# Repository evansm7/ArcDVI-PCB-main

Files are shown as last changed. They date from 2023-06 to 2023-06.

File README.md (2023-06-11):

# ArcDVI main board

Kicad 6.0 PCB design for the ArcDVI main board:

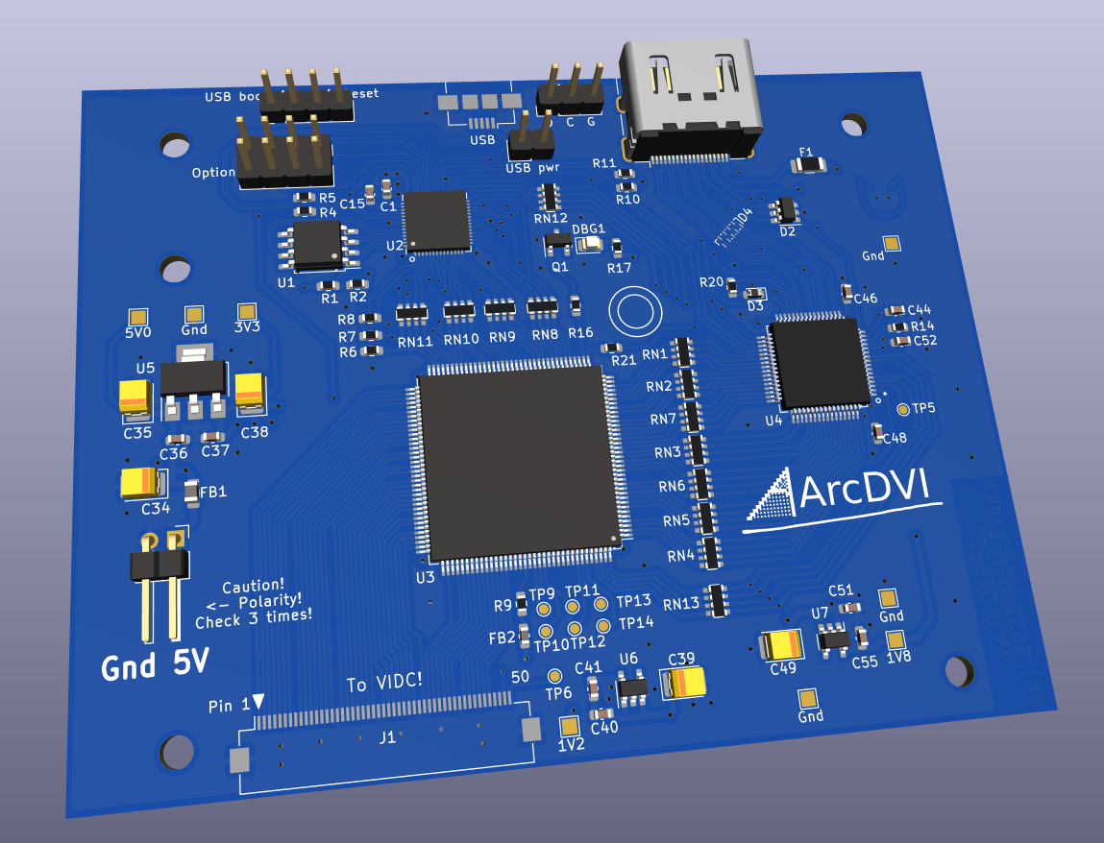
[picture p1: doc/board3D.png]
3D board


This board interfaces via FFC to an ArcDVI VIDC board (either the socket-based interposer for A4xx machines, or the push-on for A3000/A5000).

See <https://stardot.org.uk> for more info.

# License

ArcDVI is copyright 2023 Matt Evans.

This work is licensed under the Creative Commons Attribution-NonCommercial-ShareAlike 3.0 Unported License. To view a copy of this license, visit http://creativecommons.org/licenses/by-nc-sa/3.0/ or send a letter to Creative Commons, PO Box 1866, Mountain View, CA 94042, USA.

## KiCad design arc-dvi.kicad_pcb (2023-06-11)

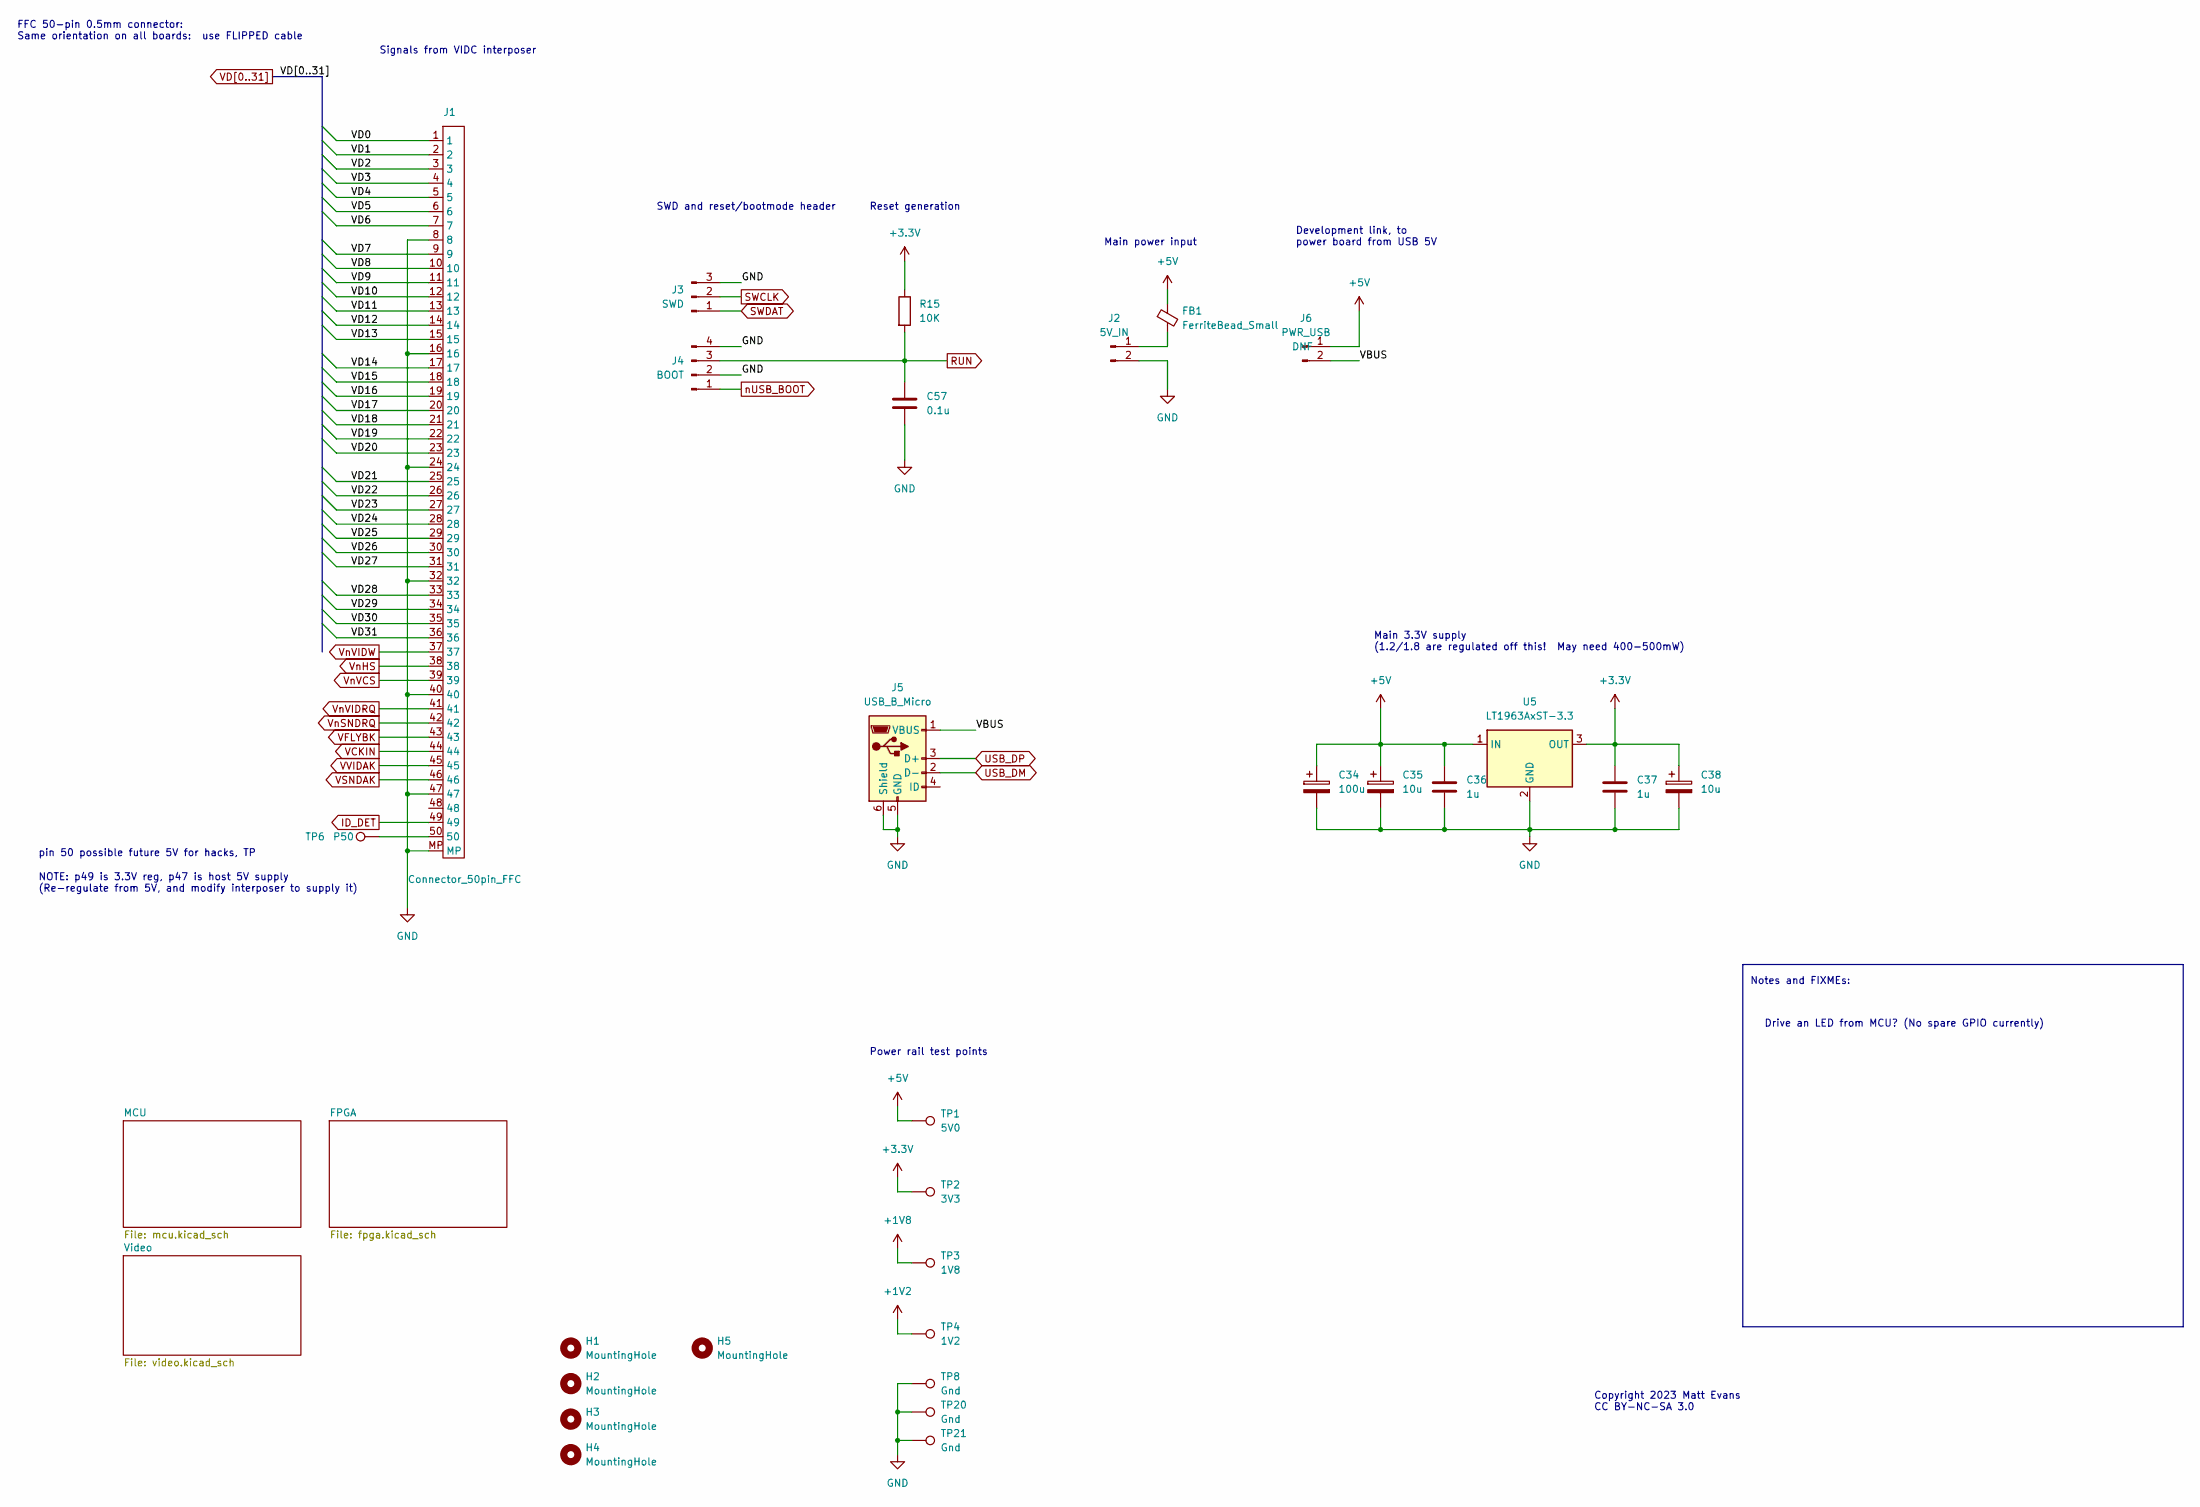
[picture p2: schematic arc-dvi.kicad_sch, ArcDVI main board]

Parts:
C34: 100u; CP_EIA-3528-21_Kemet-B
C35, C38: 10u; CP_EIA-3528-21_Kemet-B
C36, C37: 1u; C_0603_1608Metric
C57: 0.1u; C_0603_1608Metric
FB1: FerriteBead_Small; L_0805_2012Metric
H1, H2, H3, H4, H5: MountingHole; MountingHole_3.2mm_M3
J1: Connector_50pin_FFC; Hirose_FH12-50S-0.5SH_1x50-1MP_P0.50mm_Horizontal
J2: 5V_IN; PinHeader_1x02_P2.54mm_Horizontal
J3: SWD; PinHeader_1x03_P2.54mm_Vertical
J4: BOOT; PinHeader_1x04_P2.54mm_Vertical
J5: USB_B_Micro; USB_Micro-B_Amphenol_10104110_Horizontal
J6: PWR_USB; PinHeader_1x02_P2.54mm_Vertical
R15: 10K; R_0603_1608Metric
TP1: 5V0; TestPoint_Pad_1.5x1.5mm
TP2: 3V3; TestPoint_Pad_1.5x1.5mm
TP3: 1V8; TestPoint_Pad_1.5x1.5mm
TP4: 1V2; TestPoint_Pad_1.5x1.5mm
TP6: P50; TestPoint_Pad_D1.0mm
TP8, TP20, TP21: Gnd; TestPoint_Pad_1.5x1.5mm
U5: LT1963AxST-3.3; SOT-223-3_TabPin2

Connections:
+1V2: TP4.1; also elsewhere on the board
+1V8: TP3.1; also elsewhere on the board
+3V3: C37.1, C38.1, R15.1, TP2.1, U5.3 (OUT); also elsewhere on the board
+5V: C34.1, C35.1, C36.1, FB1.1, J6.1, TP1.1, U5.1 (IN); also elsewhere on the board
/VBUS: J5.1 (VBUS), J6.2
GND: C34.2, C35.2, C36.2, C37.2, C38.2, C57.2, J1.8, J1.16, J1.24, J1.32, J1.40, J1.47, J1.MP, J2.2, J3.3, J4.2, J4.4, J5.5 (GND), J5.6 (Shield), TP8.1, TP20.1, TP21.1, U5.2 (GND); also elsewhere on the board
ID_DET: J1.49; also elsewhere on the board
unnamed: FB1.2, J2.1
unnamed: J1.50, TP6.1
RUN: C57.1, J4.3, R15.2; also elsewhere on the board
SWCLK: J3.2; also elsewhere on the board
SWDAT: J3.1; also elsewhere on the board
USB_DM: J5.2 (D-); also elsewhere on the board
USB_DP: J5.3 (D+); also elsewhere on the board
VCKIN: J1.44; also elsewhere on the board
VD0: J1.1; also elsewhere on the board
VD1: J1.2; also elsewhere on the board
VD2: J1.3; also elsewhere on the board
VD3: J1.4; also elsewhere on the board
VD4: J1.5; also elsewhere on the board
VD5: J1.6; also elsewhere on the board
VD6: J1.7; also elsewhere on the board
VD7: J1.9; also elsewhere on the board
VD8: J1.10; also elsewhere on the board
VD9: J1.11; also elsewhere on the board
VD10: J1.12; also elsewhere on the board
VD11: J1.13; also elsewhere on the board
VD12: J1.14; also elsewhere on the board
VD13: J1.15; also elsewhere on the board
VD14: J1.17; also elsewhere on the board
VD15: J1.18; also elsewhere on the board
VD16: J1.19; also elsewhere on the board
VD17: J1.20; also elsewhere on the board
VD18: J1.21; also elsewhere on the board
VD19: J1.22; also elsewhere on the board
VD20: J1.23; also elsewhere on the board
VD21: J1.25; also elsewhere on the board
VD22: J1.26; also elsewhere on the board
VD23: J1.27; also elsewhere on the board
VD24: J1.28; also elsewhere on the board
VD25: J1.29; also elsewhere on the board
VD26: J1.30; also elsewhere on the board
VD27: J1.31; also elsewhere on the board
VD28: J1.33; also elsewhere on the board
VD29: J1.34; also elsewhere on the board
VD30: J1.35; also elsewhere on the board
VD31: J1.36; also elsewhere on the board
VFLYBK: J1.43; also elsewhere on the board
VSNDAK: J1.46; also elsewhere on the board
VVIDAK: J1.45; also elsewhere on the board
VnHS: J1.38; also elsewhere on the board
VnSNDRQ: J1.42; also elsewhere on the board
VnVCS: J1.39; also elsewhere on the board
VnVIDRQ: J1.41; also elsewhere on the board
VnVIDW: J1.37; also elsewhere on the board
nUSB_BOOT: J4.1; also elsewhere on the board

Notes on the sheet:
Reset generation
Notes and FIXMEs:
Power rail test points
Copyright 2023 Matt Evans CC BY-NC-SA 3.0
Development link, to power board from USB 5V
NOTE: p49 is 3.3V reg, p47 is host 5V supply (Re-regulate from 5V, and modify interposer to supply it)
Main 3.3V supply (1.2/1.8 are regulated off this! May need 400-500mW)
Signals from VIDC interposer
SWD and reset/bootmode header
pin 50 possible future 5V for hacks, TP
Drive an LED from MCU? (No spare GPIO currently)
FFC 50-pin 0.5mm connector: Same orientation on all boards: use FLIPPED cable
Main power input

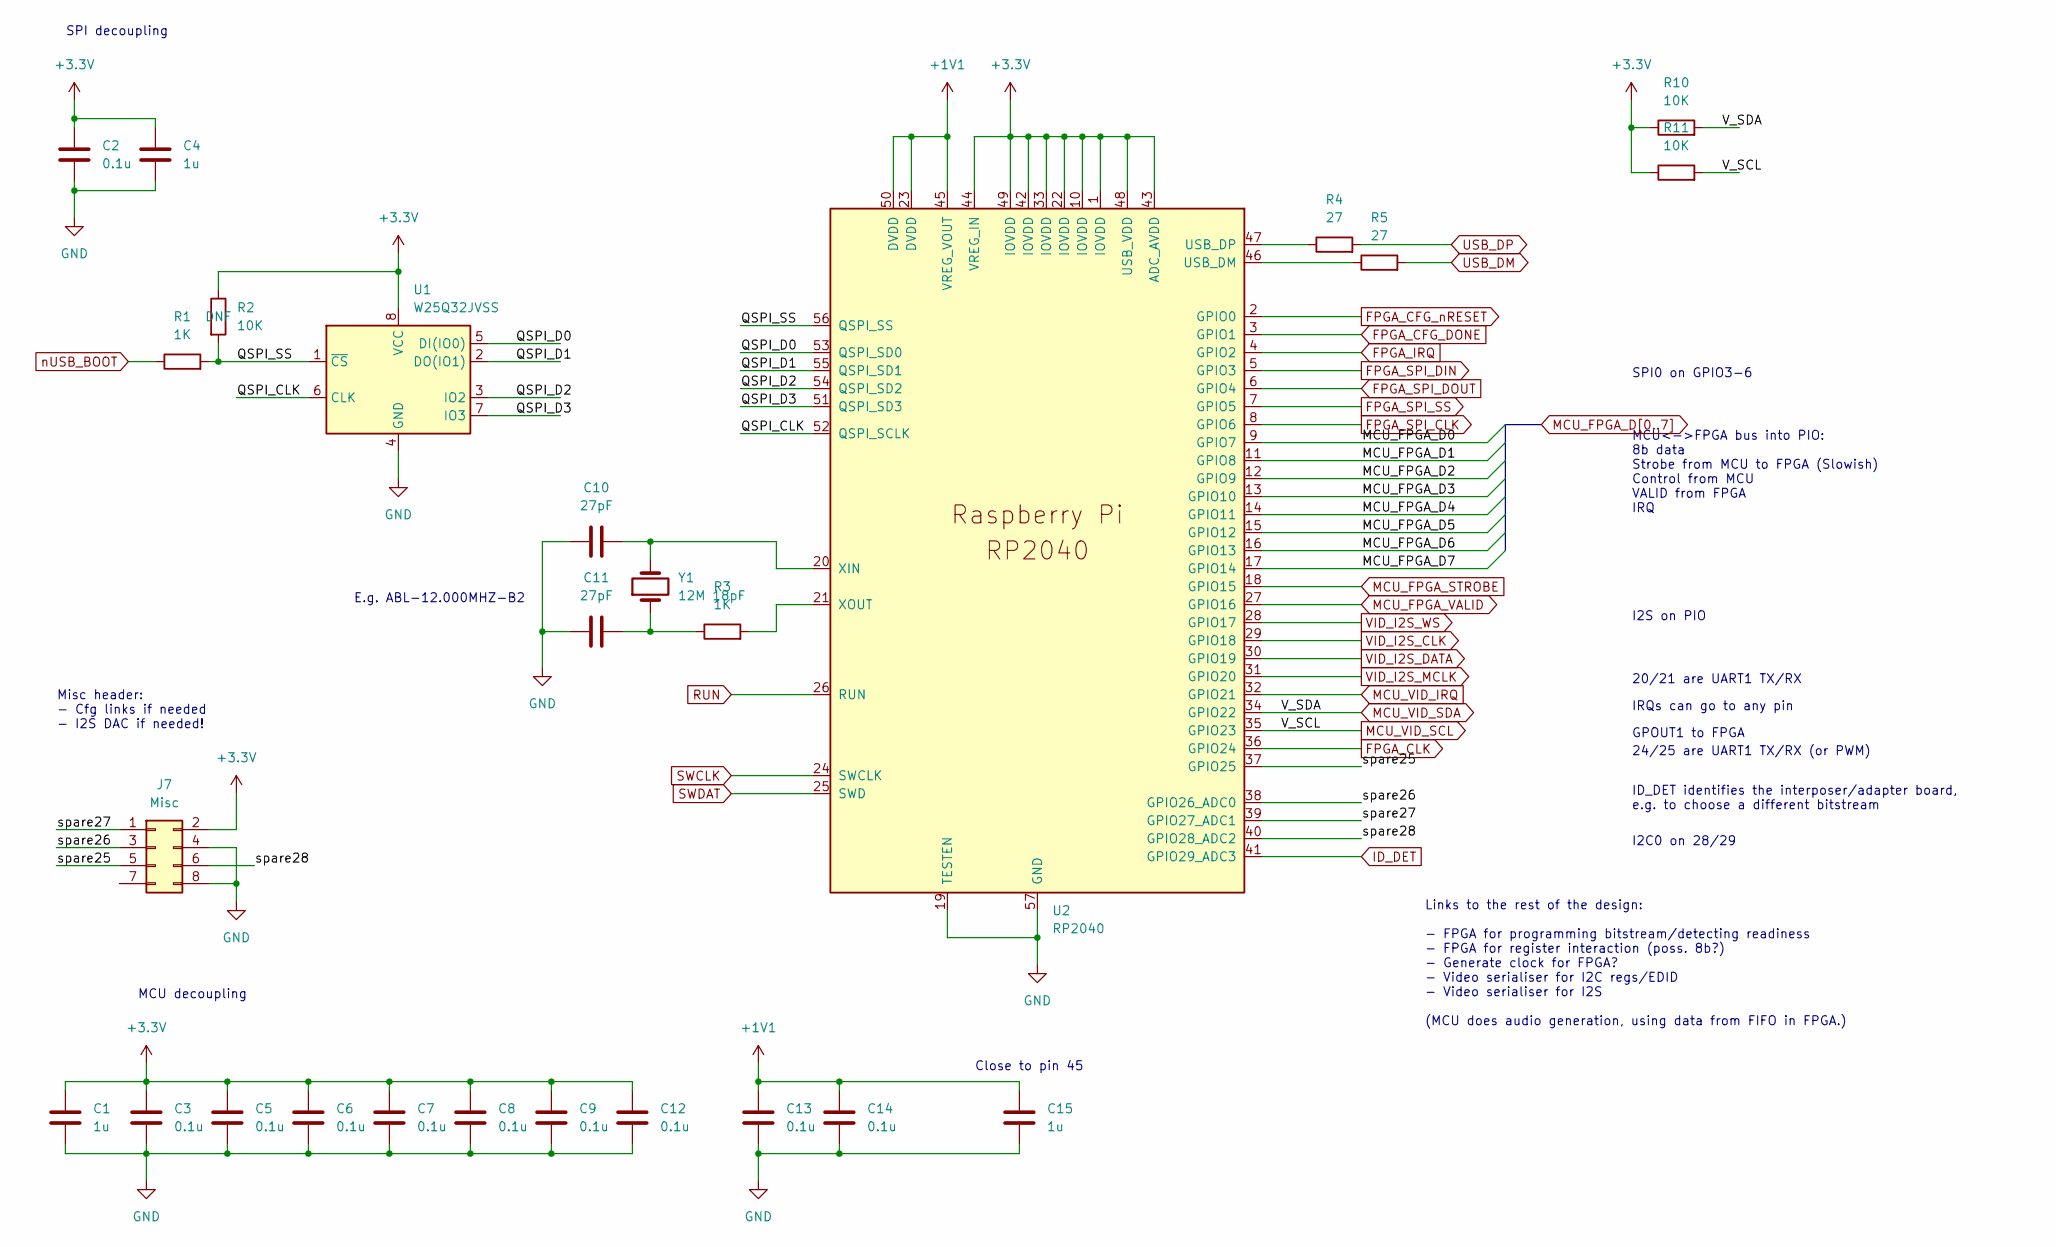
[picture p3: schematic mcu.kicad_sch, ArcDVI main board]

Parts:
C1, C4, C15: 1u; C_0603_1608Metric
C2, C3, C5, C6, C7, C8, C9, C12, C13, C14: 0.1u; C_0603_1608Metric
C10, C11: 27pF; C_0603_1608Metric
J7: Misc; PinHeader_2x04_P2.54mm_Vertical
R1, R3: 1K; R_0603_1608Metric
R2, R10, R11: 10K; R_0603_1608Metric
R4, R5: 27; R_0603_1608Metric
U1: W25Q32JVSS; SOIC-8_5.23x5.23mm_P1.27mm
U2: RP2040; RP2040-QFN-56
Y1: 12M 18pF; Crystal_SMD_ABLS7M

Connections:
+1V1: C13.1, C14.1, C15.1, U2.23 (DVDD), U2.45 (VREG_VOUT), U2.50 (DVDD)
+3V3: C1.1, C2.1, C3.1, C4.1, C5.1, C6.1, C7.1, C8.1, C9.1, C12.1, J7.2, R2.1, R10.1, R11.1, U1.8 (VCC), U2.1 (IOVDD), U2.10 (IOVDD), U2.22 (IOVDD), U2.33 (IOVDD), U2.42 (IOVDD), U2.43 (ADC_AVDD), U2.44 (VREG_IN), U2.48 (USB_VDD), U2.49 (IOVDD); also elsewhere on the board
/MCU/QSPI_CLK: U1.6 (CLK), U2.52 (QSPI_SCLK)
/MCU/QSPI_D0: U1.5 (DI(IO0)), U2.53 (QSPI_SD0)
/MCU/QSPI_D1: U1.2 (DO(IO1)), U2.55 (QSPI_SD1)
/MCU/QSPI_D2: U1.3 (IO2), U2.54 (QSPI_SD2)
/MCU/QSPI_D3: U1.7 (IO3), U2.51 (QSPI_SD3)
/MCU/QSPI_SS: R1.2, R2.2, U1.1 (~CS), U2.56 (QSPI_SS)
/MCU/spare25: J7.5, U2.37 (GPIO25)
/MCU/spare26: J7.3, U2.38 (GPIO26_ADC0)
/MCU/spare27: J7.1, U2.39 (GPIO27_ADC1)
/MCU/spare28: J7.6, U2.40 (GPIO28_ADC2)
FPGA_CFG_DONE: U2.3 (GPIO1); also elsewhere on the board
FPGA_CFG_nRESET: U2.2 (GPIO0); also elsewhere on the board
FPGA_CLK: U2.36 (GPIO24); also elsewhere on the board
FPGA_IRQ: U2.4 (GPIO2); also elsewhere on the board
FPGA_SPI_CLK: U2.8 (GPIO6); also elsewhere on the board
FPGA_SPI_DIN: U2.5 (GPIO3); also elsewhere on the board
FPGA_SPI_DOUT: U2.6 (GPIO4); also elsewhere on the board
FPGA_SPI_SS: U2.7 (GPIO5); also elsewhere on the board
GND: C1.2, C2.2, C3.2, C4.2, C5.2, C6.2, C7.2, C8.2, C9.2, C10.1, C11.1, C12.2, C13.2, C14.2, C15.2, J7.4, J7.8, U1.4 (GND), U2.19 (TESTEN), U2.57 (GND); also elsewhere on the board
ID_DET: U2.41 (GPIO29_ADC3); also elsewhere on the board
MCU_FPGA_D0: U2.9 (GPIO7); also elsewhere on the board
MCU_FPGA_D1: U2.11 (GPIO8); also elsewhere on the board
MCU_FPGA_D2: U2.12 (GPIO9); also elsewhere on the board
MCU_FPGA_D3: U2.13 (GPIO10); also elsewhere on the board
MCU_FPGA_D4: U2.14 (GPIO11); also elsewhere on the board
MCU_FPGA_D5: U2.15 (GPIO12); also elsewhere on the board
MCU_FPGA_D6: U2.16 (GPIO13); also elsewhere on the board
MCU_FPGA_D7: U2.17 (GPIO14); also elsewhere on the board
MCU_FPGA_STROBE: U2.18 (GPIO15); also elsewhere on the board
MCU_FPGA_VALID: U2.27 (GPIO16); also elsewhere on the board
MCU_VID_IRQ: U2.32 (GPIO21); also elsewhere on the board
MCU_VID_SCL: R11.2, U2.35 (GPIO23); also elsewhere on the board
MCU_VID_SDA: R10.2, U2.34 (GPIO22); also elsewhere on the board
unnamed: C10.2, U2.20 (XIN), Y1.2
unnamed: C11.2, R3.1, Y1.1
unnamed: R3.2, U2.21 (XOUT)
unnamed: R4.1, U2.47 (USB_DP)
unnamed: R5.1, U2.46 (USB_DM)
RUN: U2.26 (RUN); also elsewhere on the board
SWCLK: U2.24 (SWCLK); also elsewhere on the board
SWDAT: U2.25 (SWD); also elsewhere on the board
USB_DM: R5.2; also elsewhere on the board
USB_DP: R4.2; also elsewhere on the board
VID_I2S_CLK: U2.29 (GPIO18); also elsewhere on the board
VID_I2S_DATA: U2.30 (GPIO19); also elsewhere on the board
VID_I2S_MCLK: U2.31 (GPIO20); also elsewhere on the board
VID_I2S_WS: U2.28 (GPIO17); also elsewhere on the board
nUSB_BOOT: R1.1; also elsewhere on the board

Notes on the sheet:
MCU decoupling
20/21 are UART1 TX/RX
Misc header: - Cfg links if needed - I2S DAC if needed!
Links to the rest of the design: - FPGA for programming bitstream/detecting readiness - FPGA for register interaction (poss. 8b?) - Generate clock for FPGA? - Video serialiser for I2C regs/EDID - Video serialiser for I2S (MCU does audio generation, using data from FIFO in FPGA.)
IRQs can go to any pin
E.g. ABL-12.000MHZ-B2
I2S on PIO
GPOUT1 to FPGA
SPI decoupling
24/25 are UART1 TX/RX (or PWM)
I2C0 on 28/29
Close to pin 45
MCU<->FPGA bus into PIO: 8b data Strobe from MCU to FPGA (Slowish) Control from MCU VALID from FPGA IRQ
SPI0 on GPIO3-6
ID_DET identifies the interposer/adapter board, e.g. to choose a different bitstream

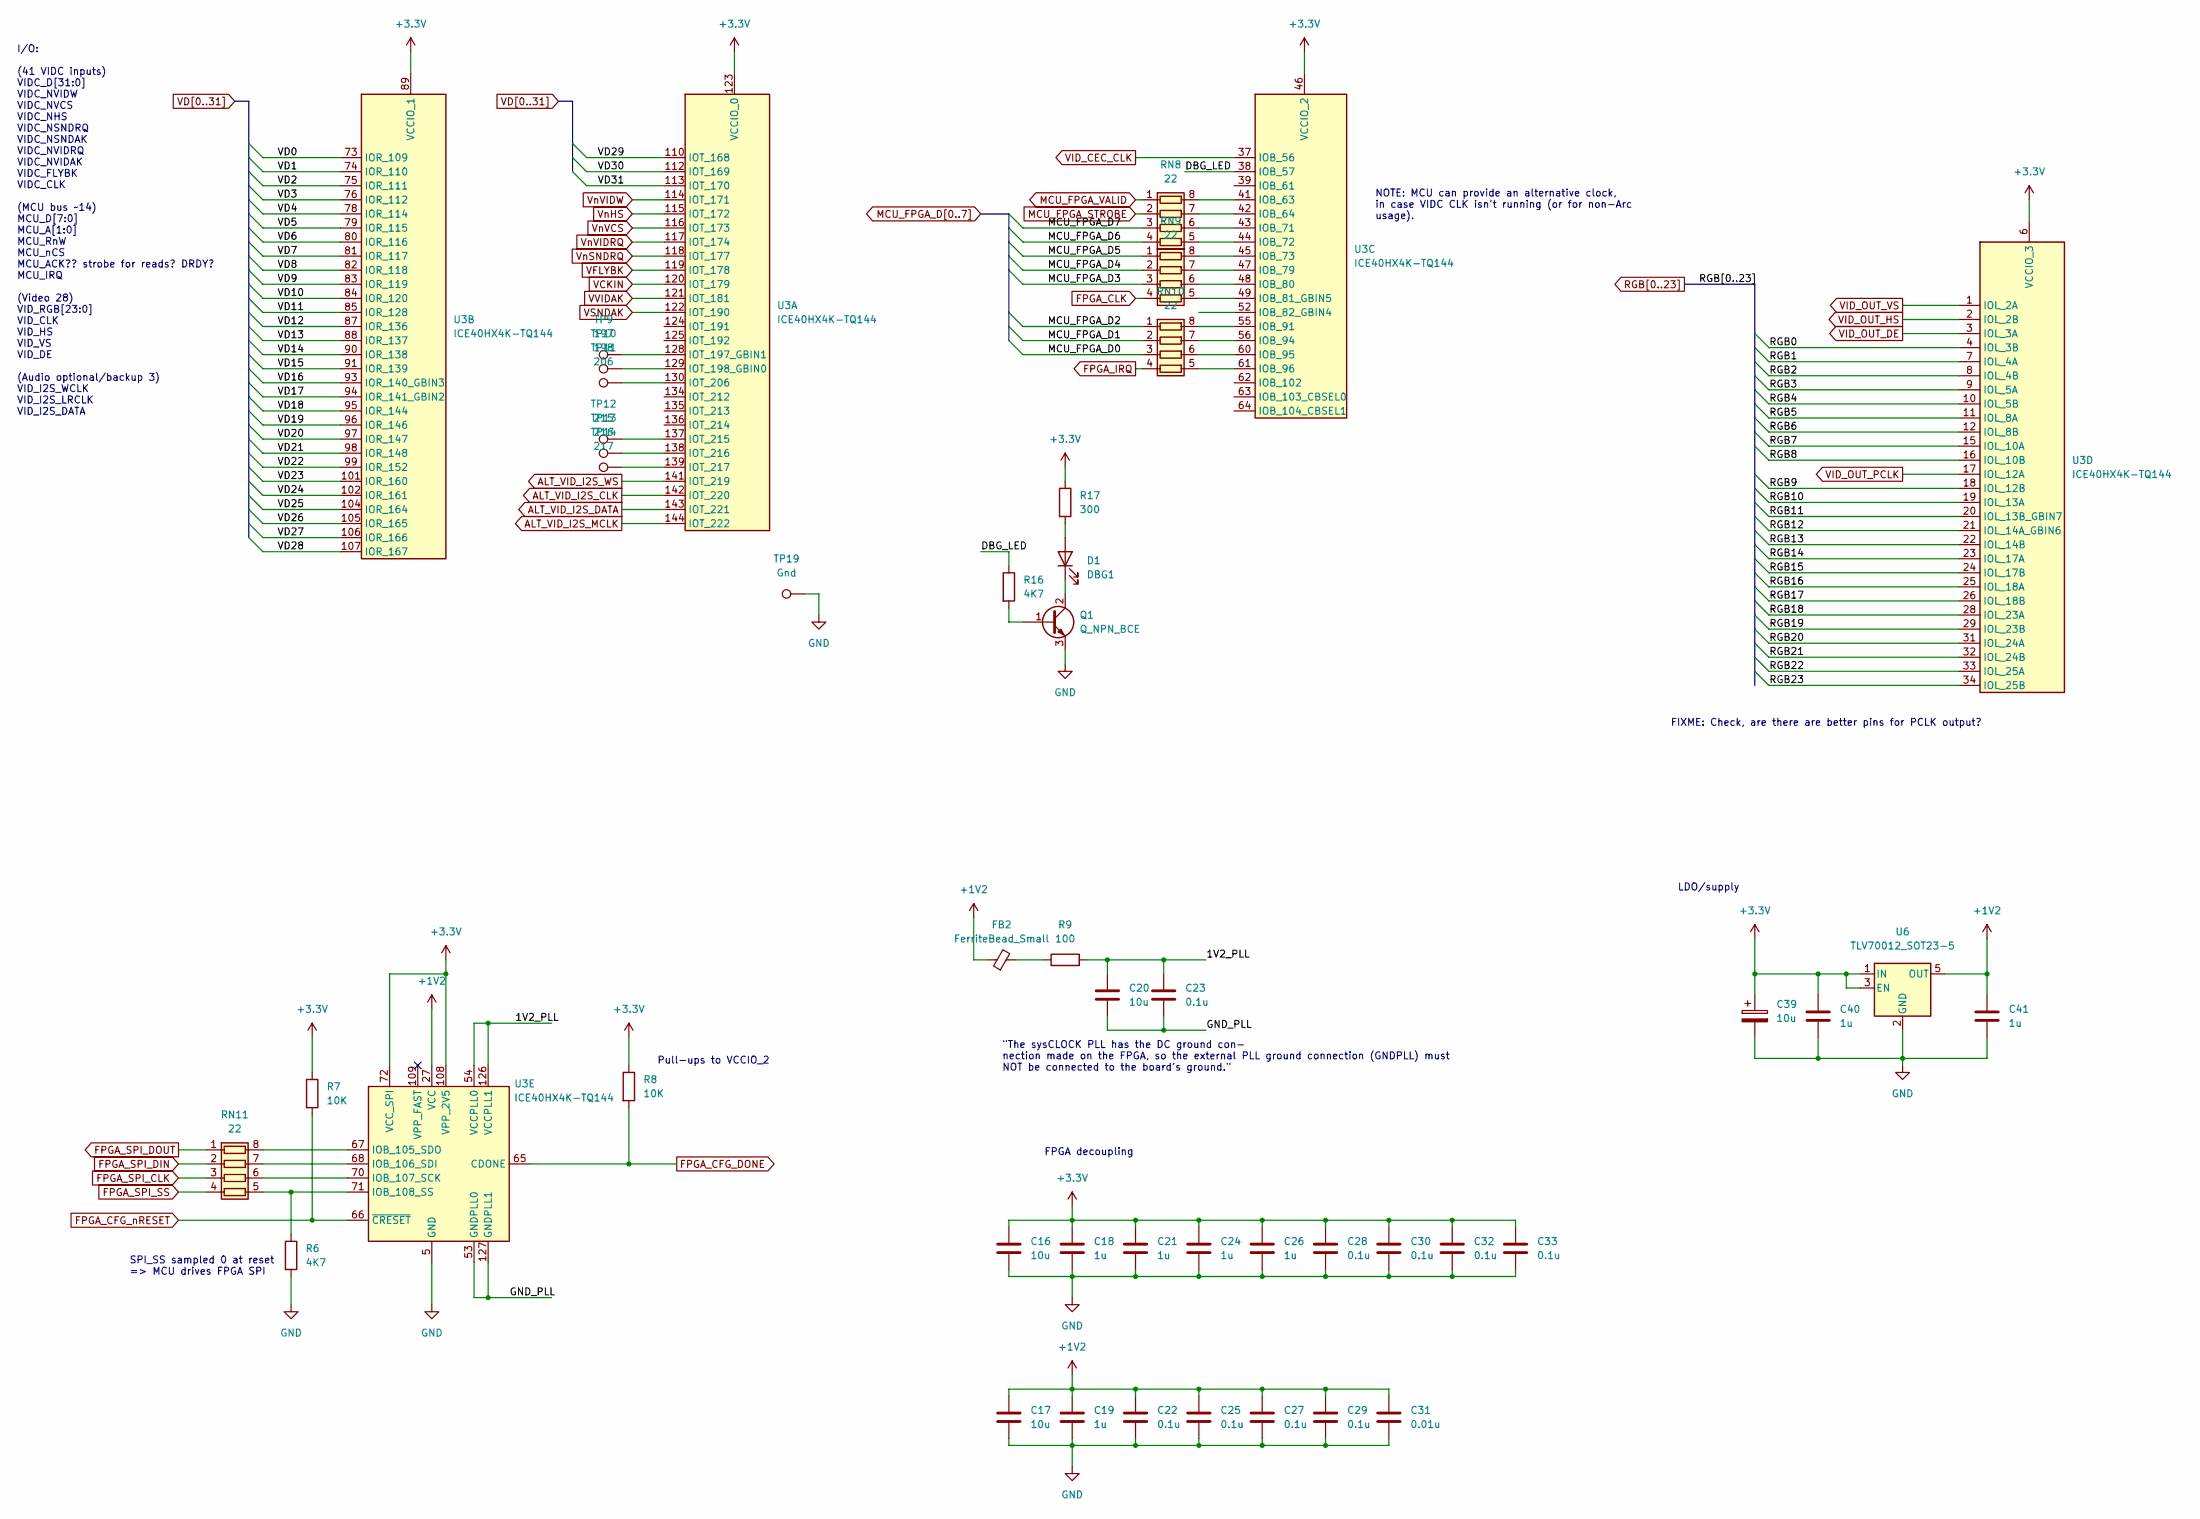
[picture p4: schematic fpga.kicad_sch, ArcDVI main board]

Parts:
C16, C17, C20: 10u; C_0805_2012Metric
C18, C19, C21, C24, C26, C40, C41: 1u; C_0603_1608Metric
C22, C23, C25, C27, C28, C29, C30, C32, C33: 0.1u; C_0603_1608Metric
C31: 0.01u; C_0603_1608Metric
C39: 10u; CP_EIA-3528-21_Kemet-B
D1: DBG1; LED_0805_2012Metric
FB2: FerriteBead_Small; L_0603_1608Metric
Q1: Q_NPN_BCE; SOT-23
R6, R16: 4K7; R_0603_1608Metric
R7, R8: 10K; R_0603_1608Metric
R9: 100; R_0603_1608Metric
R17: 300; R_0603_1608Metric
RN8, RN9, RN10, RN11: 22; R_Array_Convex_4x0603
TP9: 197; TestPoint_Pad_D1.0mm
TP10: 198; TestPoint_Pad_D1.0mm
TP11: 206; TestPoint_Pad_D1.0mm
TP12: 215; TestPoint_Pad_D1.0mm
TP13: 216; TestPoint_Pad_D1.0mm
TP14: 217; TestPoint_Pad_D1.0mm
TP19: Gnd; TestPoint_Pad_1.5x1.5mm
U3: ICE40HX4K-TQ144; TQFP-144_20x20mm_P0.5mm
U6: TLV70012_SOT23-5; SOT-23-5

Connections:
+1V2: C17.1, C19.1, C22.1, C25.1, C27.1, C29.1, C31.1, C41.1, FB2.1, U3.27 (VCC), U3.40 (VCC), U3.92 (VCC), U3.111 (VCC), U6.5 (OUT); also elsewhere on the board
+3V3: C16.1, C18.1, C21.1, C24.1, C26.1, C28.1, C30.1, C32.1, C33.1, C39.1, C40.1, R7.1, R8.1, R17.1, U3.6 (VCCIO_3), U3.30 (VCCIO_3), U3.46 (VCCIO_2), U3.57 (VCCIO_2), U3.72 (VCC_SPI), U3.89 (VCCIO_1), U3.100 (VCCIO_1), U3.108 (VPP_2V5), U3.123 (VCCIO_0), U3.131 (VCCIO_0), U6.1 (IN), U6.3 (EN); also elsewhere on the board
/FPGA/1V2_PLL: C20.1, C23.1, R9.2, U3.54 (VCCPLL0), U3.126 (VCCPLL1)
/FPGA/DBG_LED: R16.1, U3.38 (IOB_57)
/FPGA/GND_PLL: C20.2, C23.2, U3.53 (GNDPLL0), U3.127 (GNDPLL1)
ALT_VID_I2S_CLK: U3.142 (IOT_220); also elsewhere on the board
ALT_VID_I2S_DATA: U3.143 (IOT_221); also elsewhere on the board
ALT_VID_I2S_MCLK: U3.144 (IOT_222); also elsewhere on the board
ALT_VID_I2S_WS: U3.141 (IOT_219); also elsewhere on the board
FPGA_CFG_DONE: R8.2, U3.65 (CDONE); also elsewhere on the board
FPGA_CFG_nRESET: R7.2, U3.66 (~CRESET); also elsewhere on the board
FPGA_CLK: RN9.4 (R4.1); also elsewhere on the board
FPGA_IRQ: RN10.4 (R4.1); also elsewhere on the board
FPGA_SPI_CLK: RN11.3 (R3.1); also elsewhere on the board
FPGA_SPI_DIN: RN11.2 (R2.1); also elsewhere on the board
FPGA_SPI_DOUT: RN11.1 (R1.1); also elsewhere on the board
FPGA_SPI_SS: RN11.4 (R4.1); also elsewhere on the board
GND: C16.2, C17.2, C18.2, C19.2, C21.2, C22.2, C24.2, C25.2, C26.2, C27.2, C28.2, C29.2, C30.2, C31.2, C32.2, C33.2, C39.2, C40.2, C41.2, Q1.3 (E), R6.2, TP19.1, U3.5 (GND), U3.13 (GND), U3.14 (GND), U3.59 (GND), U3.69 (GND), U3.86 (GND), U3.103 (GND), U3.132 (GND), U3.140 (GND), U6.2 (GND); also elsewhere on the board
MCU_FPGA_D0: RN10.3 (R3.1); also elsewhere on the board
MCU_FPGA_D1: RN10.2 (R2.1); also elsewhere on the board
MCU_FPGA_D2: RN10.1 (R1.1); also elsewhere on the board
MCU_FPGA_D3: RN9.3 (R3.1); also elsewhere on the board
MCU_FPGA_D4: RN9.2 (R2.1); also elsewhere on the board
MCU_FPGA_D5: RN9.1 (R1.1); also elsewhere on the board
MCU_FPGA_D6: RN8.4 (R4.1); also elsewhere on the board
MCU_FPGA_D7: RN8.3 (R3.1); also elsewhere on the board
MCU_FPGA_STROBE: RN8.2 (R2.1); also elsewhere on the board
MCU_FPGA_VALID: RN8.1 (R1.1); also elsewhere on the board
unnamed: D1.1 (K), Q1.2 (C)
unnamed: D1.2 (A), R17.2
unnamed: FB2.2, R9.1
unnamed: Q1.1 (B), R16.2
unnamed: R6.1, RN11.5 (R4.2), U3.71 (IOB_108_SS)
unnamed: RN8.5 (R4.2), U3.44 (IOB_72)
unnamed: RN8.6 (R3.2), U3.43 (IOB_71)
unnamed: RN8.7 (R2.2), U3.42 (IOB_64)
unnamed: RN8.8 (R1.2), U3.41 (IOB_63)
unnamed: RN9.5 (R4.2), U3.49 (IOB_81_GBIN5)
unnamed: RN9.6 (R3.2), U3.48 (IOB_80)
unnamed: RN9.7 (R2.2), U3.47 (IOB_79)
unnamed: RN9.8 (R1.2), U3.45 (IOB_73)
unnamed: RN10.5 (R4.2), U3.61 (IOB_96)
unnamed: RN10.6 (R3.2), U3.60 (IOB_95)
unnamed: RN10.7 (R2.2), U3.56 (IOB_94)
unnamed: RN10.8 (R1.2), U3.55 (IOB_91)
unnamed: RN11.6 (R3.2), U3.70 (IOB_107_SCK)
unnamed: RN11.7 (R2.2), U3.68 (IOB_106_SDI)
unnamed: RN11.8 (R1.2), U3.67 (IOB_105_SDO)
unnamed: TP9.1, U3.128 (IOT_197_GBIN1)
unnamed: TP10.1, U3.129 (IOT_198_GBIN0)
unnamed: TP11.1, U3.130 (IOT_206)
unnamed: TP12.1, U3.137 (IOT_215)
unnamed: TP13.1, U3.138 (IOT_216)
unnamed: TP14.1, U3.139 (IOT_217)
RGB0: U3.4 (IOL_3B); also elsewhere on the board
RGB1: U3.7 (IOL_4A); also elsewhere on the board
RGB2: U3.8 (IOL_4B); also elsewhere on the board
RGB3: U3.9 (IOL_5A); also elsewhere on the board
RGB4: U3.10 (IOL_5B); also elsewhere on the board
RGB5: U3.11 (IOL_8A); also elsewhere on the board
RGB6: U3.12 (IOL_8B); also elsewhere on the board
RGB7: U3.15 (IOL_10A); also elsewhere on the board
RGB8: U3.16 (IOL_10B); also elsewhere on the board
RGB9: U3.18 (IOL_12B); also elsewhere on the board
RGB10: U3.19 (IOL_13A); also elsewhere on the board
RGB11: U3.20 (IOL_13B_GBIN7); also elsewhere on the board
RGB12: U3.21 (IOL_14A_GBIN6); also elsewhere on the board
RGB13: U3.22 (IOL_14B); also elsewhere on the board
RGB14: U3.23 (IOL_17A); also elsewhere on the board
RGB15: U3.24 (IOL_17B); also elsewhere on the board
RGB16: U3.25 (IOL_18A); also elsewhere on the board
RGB17: U3.26 (IOL_18B); also elsewhere on the board
RGB18: U3.28 (IOL_23A); also elsewhere on the board
RGB19: U3.29 (IOL_23B); also elsewhere on the board
RGB20: U3.31 (IOL_24A); also elsewhere on the board
RGB21: U3.32 (IOL_24B); also elsewhere on the board
RGB22: U3.33 (IOL_25A); also elsewhere on the board
RGB23: U3.34 (IOL_25B); also elsewhere on the board
VCKIN: U3.120 (IOT_179); also elsewhere on the board
VD0: U3.73 (IOR_109); also elsewhere on the board
VD1: U3.74 (IOR_110); also elsewhere on the board
VD2: U3.75 (IOR_111); also elsewhere on the board
VD3: U3.76 (IOR_112); also elsewhere on the board
VD4: U3.78 (IOR_114); also elsewhere on the board
VD5: U3.79 (IOR_115); also elsewhere on the board
VD6: U3.80 (IOR_116); also elsewhere on the board
VD7: U3.81 (IOR_117); also elsewhere on the board
VD8: U3.82 (IOR_118); also elsewhere on the board
VD9: U3.83 (IOR_119); also elsewhere on the board
VD10: U3.84 (IOR_120); also elsewhere on the board
VD11: U3.85 (IOR_128); also elsewhere on the board
VD12: U3.87 (IOR_136); also elsewhere on the board
VD13: U3.88 (IOR_137); also elsewhere on the board
VD14: U3.90 (IOR_138); also elsewhere on the board
VD15: U3.91 (IOR_139); also elsewhere on the board
VD16: U3.93 (IOR_140_GBIN3); also elsewhere on the board
VD17: U3.94 (IOR_141_GBIN2); also elsewhere on the board
VD18: U3.95 (IOR_144); also elsewhere on the board
VD19: U3.96 (IOR_146); also elsewhere on the board
VD20: U3.97 (IOR_147); also elsewhere on the board
VD21: U3.98 (IOR_148); also elsewhere on the board
VD22: U3.99 (IOR_152); also elsewhere on the board
VD23: U3.101 (IOR_160); also elsewhere on the board
VD24: U3.102 (IOR_161); also elsewhere on the board
VD25: U3.104 (IOR_164); also elsewhere on the board
VD26: U3.105 (IOR_165); also elsewhere on the board
VD27: U3.106 (IOR_166); also elsewhere on the board
VD28: U3.107 (IOR_167); also elsewhere on the board
VD29: U3.110 (IOT_168); also elsewhere on the board
VD30: U3.112 (IOT_169); also elsewhere on the board
VD31: U3.113 (IOT_170); also elsewhere on the board
VFLYBK: U3.119 (IOT_178); also elsewhere on the board
VID_CEC_CLK: U3.37 (IOB_56); also elsewhere on the board
VID_OUT_DE: U3.3 (IOL_3A); also elsewhere on the board
VID_OUT_HS: U3.2 (IOL_2B); also elsewhere on the board
VID_OUT_PCLK: U3.17 (IOL_12A); also elsewhere on the board
VID_OUT_VS: U3.1 (IOL_2A); also elsewhere on the board
VSNDAK: U3.122 (IOT_190); also elsewhere on the board
VVIDAK: U3.121 (IOT_181); also elsewhere on the board
VnHS: U3.115 (IOT_172); also elsewhere on the board
VnSNDRQ: U3.118 (IOT_177); also elsewhere on the board
VnVCS: U3.116 (IOT_173); also elsewhere on the board
VnVIDRQ: U3.117 (IOT_174); also elsewhere on the board
VnVIDW: U3.114 (IOT_171); also elsewhere on the board

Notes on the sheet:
Pull-ups to VCCIO_2
SPI_SS sampled 0 at reset => MCU drives FPGA SPI
FIXME: Check, are there are better pins for PCLK output?
LDO/supply
"The sysCLOCK PLL has the DC ground con- nection made on the FPGA, so the external PLL ground connection (GNDPLL) must NOT be connected to the board's ground."
FPGA decoupling
I/O: (41 VIDC inputs) VIDC_D[31:0] VIDC_NVIDW VIDC_NVCS VIDC_NHS VIDC_NSNDRQ VIDC_NSNDAK VIDC_NVIDRQ VIDC_NVIDAK VIDC_FLYBK VIDC_CLK (MCU bus ~14) MCU_D[7:0] MCU_A[1:0] MCU_RnW MCU_nCS MCU_ACK?? strobe for reads? DRDY? MCU_IRQ (Video 28) VID_RGB[23:0] VID_CLK VID_HS VID_VS VID_DE (Audio optional/ba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
NOTE: MCU can provide an alternative clock, in case VIDC CLK isn't running (or for non-Arc usage).

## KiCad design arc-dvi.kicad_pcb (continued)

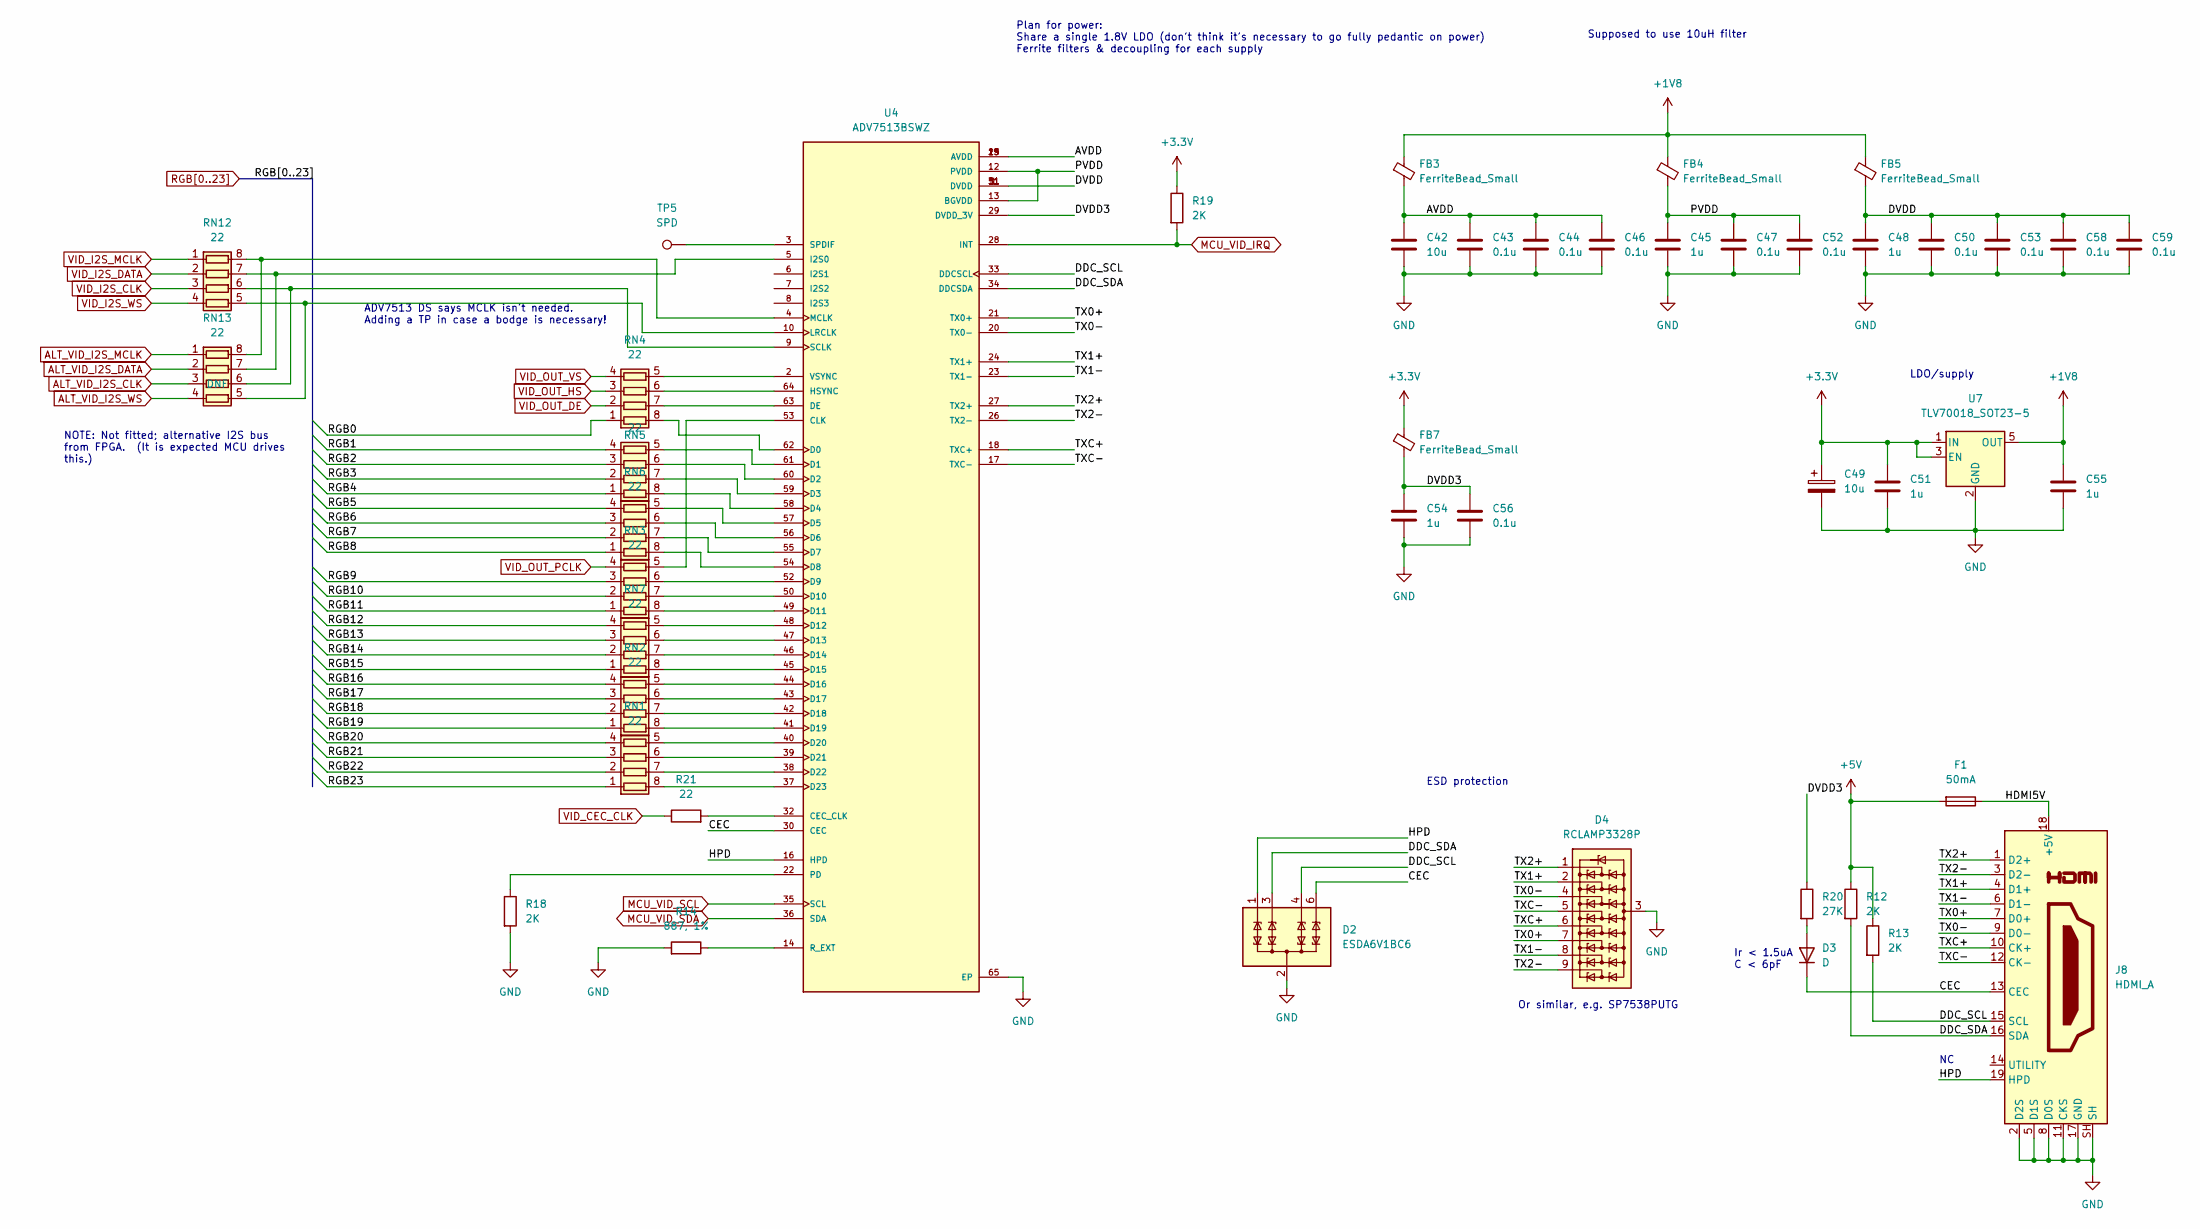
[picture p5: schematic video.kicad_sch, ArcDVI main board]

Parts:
C42: 10u; C_0603_1608Metric
C43, C44, C46, C47, C50, C52, C53, C56, C58, C59: 0.1u; C_0603_1608Metric
C45, C48, C51, C54, C55: 1u; C_0603_1608Metric
C49: 10u; CP_EIA-3528-21_Kemet-B
D2: ESDA6V1BC6; SOT-23-6
D3: D; D_0603_1608Metric
D4: RCLAMP3328P; UDFN-9_1.0x3.8mm_P0.5mm
F1: 50mA; Fuse_1206_3216Metric_Pad1.42x1.75mm_HandSolder
FB3, FB4, FB5, FB7: FerriteBead_Small; L_0603_1608Metric
J8: HDMI_A; HDMI_A_Molex_208658-1001_Horizontal
R12, R13, R18, R19: 2K; R_0603_1608Metric
R14: 887, 1%; R_0603_1608Metric
R20: 27K; R_0603_1608Metric
R21: 22; R_0603_1608Metric
RN1, RN2, RN3, RN4, RN5, RN6, RN7, RN12, RN13: 22; R_Array_Convex_4x0603
TP5: SPD; TestPoint_Pad_D1.0mm
U4: ADV7513BSWZ; QFP50P1200X1200X160-65N; PARTREV B
U7: TLV70018_SOT23-5; SOT-23-5

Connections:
+1V8: C55.1, FB3.1, FB4.1, FB5.1, U7.5 (OUT); also elsewhere on the board
+3V3: C49.1, C51.1, FB7.1, R19.1, U7.1 (IN), U7.3 (EN); also elsewhere on the board
+5V: F1.2, R12.1, R13.1; also elsewhere on the board
/Video/AVDD: C42.1, C43.1, C44.1, C46.1, FB3.2, U4.15 (AVDD), U4.19 (AVDD), U4.25 (AVDD)
/Video/CEC: D2.6 (TVS4), D3.1 (K), J8.13 (CEC), U4.30 (CEC)
/Video/DDC_SCL: D2.4 (TVS3), J8.15 (SCL), R13.2, U4.33 (DDCSCL)
/Video/DDC_SDA: D2.3 (TVS2), J8.16 (SDA), R12.2, U4.34 (DDCSDA)
/Video/DVDD: C48.1, C50.1, C53.1, C58.1, C59.1, FB5.2, U4.1 (DVDD), U4.11 (DVDD), U4.31 (DVDD), U4.51 (DVDD)
/Video/DVDD3: C54.1, C56.1, FB7.2, R20.1, U4.29 (DVDD_3V)
/Video/HDMI5V: F1.1, J8.18 (+5V)
/Video/HPD: D2.1 (TVS1), J8.19 (HPD), U4.16 (HPD)
/Video/PVDD: C45.1, C47.1, C52.1, FB4.2, U4.12 (PVDD), U4.13 (BGVDD)
/Video/TX0+: D4.7 (K6), J8.7 (D0+), U4.21 (TX0+)
/Video/TX0-: D4.4 (K3), J8.9 (D0-), U4.20 (TX0−)
/Video/TX1+: D4.2 (K2), J8.4 (D1+), U4.24 (TX1+)
/Video/TX1-: D4.8 (K7), J8.6 (D1-), U4.23 (TX1−)
/Video/TX2+: D4.1 (K1), J8.1 (D2+), U4.27 (TX2+)
/Video/TX2-: D4.9 (K8), J8.3 (D2-), U4.26 (TX2−)
/Video/TXC+: D4.6 (K5), J8.10 (CK+), U4.18 (TXC+)
/Video/TXC-: D4.5 (K4), J8.12 (CK-), U4.17 (TXC−)
ALT_VID_I2S_CLK: RN13.3 (R3.1); also elsewhere on the board
ALT_VID_I2S_DATA: RN13.2 (R2.1); also elsewhere on the board
ALT_VID_I2S_MCLK: RN13.1 (R1.1); also elsewhere on the board
ALT_VID_I2S_WS: RN13.4 (R4.1); also elsewhere on the board
GND: C42.2, C43.2, C44.2, C45.2, C46.2, C47.2, C48.2, C49.2, C50.2, C51.2, C52.2, C53.2, C54.2, C55.2, C56.2, C58.2, C59.2, D2.2 (COM), D2.5 (COM), D4.3 (A), J8.2 (D2S), J8.5 (D1S), J8.8 (D0S), J8.11 (CKS), J8.17 (GND), J8.SH, R14.2, R18.2, U4.65 (EP), U7.2 (GND); also elsewhere on the board
MCU_VID_IRQ: R19.2, U4.28 (INT); also elsewhere on the board
MCU_VID_SCL: U4.35 (SCL); also elsewhere on the board
MCU_VID_SDA: U4.36 (SDA); also elsewhere on the board
unnamed: D3.2 (A), R20.2
unnamed: R14.1, U4.14 (R_EXT)
unnamed: R18.1, U4.22 (PD)
unnamed: R21.2, U4.32 (CEC_CLK)
unnamed: RN1.5 (R4.2), U4.40 (D20)
unnamed: RN1.6 (R3.2), U4.39 (D21)
unnamed: RN1.7 (R2.2), U4.38 (D22)
unnamed: RN1.8 (R1.2), U4.37 (D23)
unnamed: RN2.5 (R4.2), U4.44 (D16)
unnamed: RN2.6 (R3.2), U4.43 (D17)
unnamed: RN2.7 (R2.2), U4.42 (D18)
unnamed: RN2.8 (R1.2), U4.41 (D19)
unnamed: RN3.5 (R4.2), U4.53 (CLK)
unnamed: RN3.6 (R3.2), U4.52 (D9)
unnamed: RN3.7 (R2.2), U4.50 (D10)
unnamed: RN3.8 (R1.2), U4.49 (D11)
unnamed: RN4.5 (R4.2), U4.2 (VSYNC)
unnamed: RN4.6 (R3.2), U4.64 (HSYNC)
unnamed: RN4.7 (R2.2), U4.63 (DE)
unnamed: RN4.8 (R1.2), U4.62 (D0)
unnamed: RN5.5 (R4.2), U4.61 (D1)
unnamed: RN5.6 (R3.2), U4.60 (D2)
unnamed: RN5.7 (R2.2), U4.59 (D3)
unnamed: RN5.8 (R1.2), U4.58 (D4)
unnamed: RN6.5 (R4.2), U4.57 (D5)
unnamed: RN6.6 (R3.2), U4.56 (D6)
unnamed: RN6.7 (R2.2), U4.55 (D7)
unnamed: RN6.8 (R1.2), U4.54 (D8)
unnamed: RN7.5 (R4.2), U4.48 (D12)
unnamed: RN7.6 (R3.2), U4.47 (D13)
unnamed: RN7.7 (R2.2), U4.46 (D14)
unnamed: RN7.8 (R1.2), U4.45 (D15)
unnamed: RN12.5 (R4.2), RN13.5 (R4.2), U4.10 (LRCLK)
unnamed: RN12.6 (R3.2), RN13.6 (R3.2), U4.9 (SCLK)
unnamed: RN12.7 (R2.2), RN13.7 (R2.2), U4.5 (I2S0)
unnamed: RN12.8 (R1.2), RN13.8 (R1.2), U4.4 (MCLK)
unnamed: TP5.1, U4.3 (SPDIF)
RGB0: RN4.1 (R1.1); also elsewhere on the board
RGB1: RN5.4 (R4.1); also elsewhere on the board
RGB2: RN5.3 (R3.1); also elsewhere on the board
RGB3: RN5.2 (R2.1); also elsewhere on the board
RGB4: RN5.1 (R1.1); also elsewhere on the board
RGB5: RN6.4 (R4.1); also elsewhere on the board
RGB6: RN6.3 (R3.1); also elsewhere on the board
RGB7: RN6.2 (R2.1); also elsewhere on the board
RGB8: RN6.1 (R1.1); also elsewhere on the board
RGB9: RN3.3 (R3.1); also elsewhere on the board
RGB10: RN3.2 (R2.1); also elsewhere on the board
RGB11: RN3.1 (R1.1); also elsewhere on the board
RGB12: RN7.4 (R4.1); also elsewhere on the board
RGB13: RN7.3 (R3.1); also elsewhere on the board
RGB14: RN7.2 (R2.1); also elsewhere on the board
RGB15: RN7.1 (R1.1); also elsewhere on the board
RGB16: RN2.4 (R4.1); also elsewhere on the board
RGB17: RN2.3 (R3.1); also elsewhere on the board
RGB18: RN2.2 (R2.1); also elsewhere on the board
RGB19: RN2.1 (R1.1); also elsewhere on the board
RGB20: RN1.4 (R4.1); also elsewhere on the board
RGB21: RN1.3 (R3.1); also elsewhere on the board
RGB22: RN1.2 (R2.1); also elsewhere on the board
RGB23: RN1.1 (R1.1); also elsewhere on the board
VID_CEC_CLK: R21.1; also elsewhere on the board
VID_I2S_CLK: RN12.3 (R3.1); also elsewhere on the board
VID_I2S_DATA: RN12.2 (R2.1); also elsewhere on the board
VID_I2S_MCLK: RN12.1 (R1.1); also elsewhere on the board
VID_I2S_WS: RN12.4 (R4.1); also elsewhere on the board
VID_OUT_DE: RN4.2 (R2.1); also elsewhere on the board
VID_OUT_HS: RN4.3 (R3.1); also elsewhere on the board
VID_OUT_PCLK: RN3.4 (R4.1); also elsewhere on the board
VID_OUT_VS: RN4.4 (R4.1); also elsewhere on the board

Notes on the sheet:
ADV7513 DS says MCLK isn't needed. Adding a TP in case a bodge is necessary!
Ir < 1.5uA C < 6pF
ESD protection
Supposed to use 10uH filter
Plan for power: Share a single 1.8V LDO (don't think it's necessary to go fully pedantic on power) Ferrite filters & decoupling for each supply
Or similar, e.g. SP7538PUTG
LDO/supply
NOTE: Not fitted; alternative I2S bus from FPGA. (It is expected MCU drives this.)

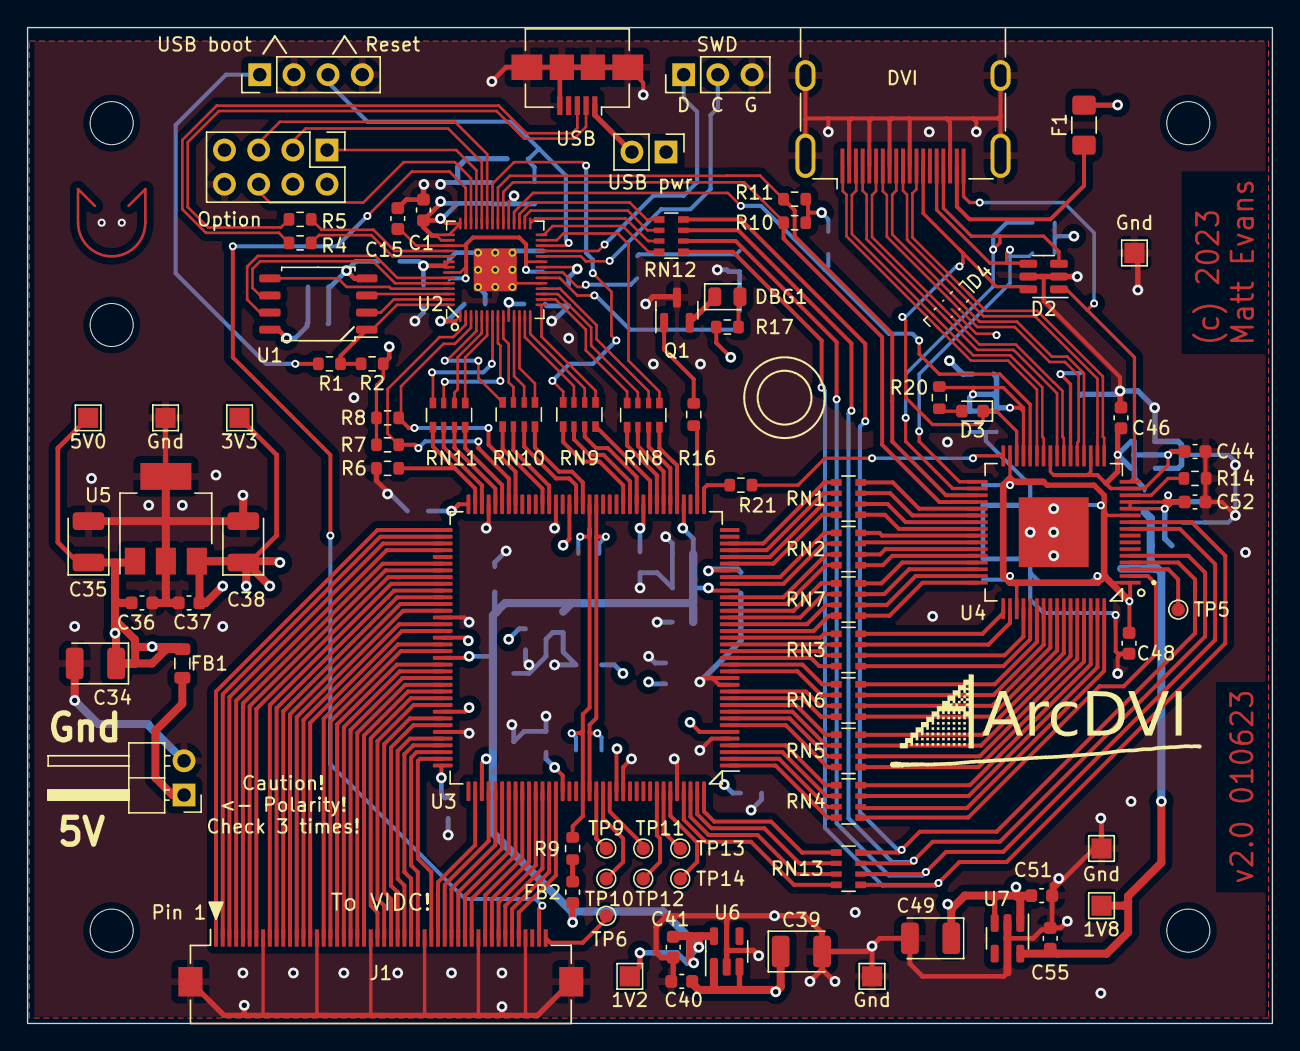
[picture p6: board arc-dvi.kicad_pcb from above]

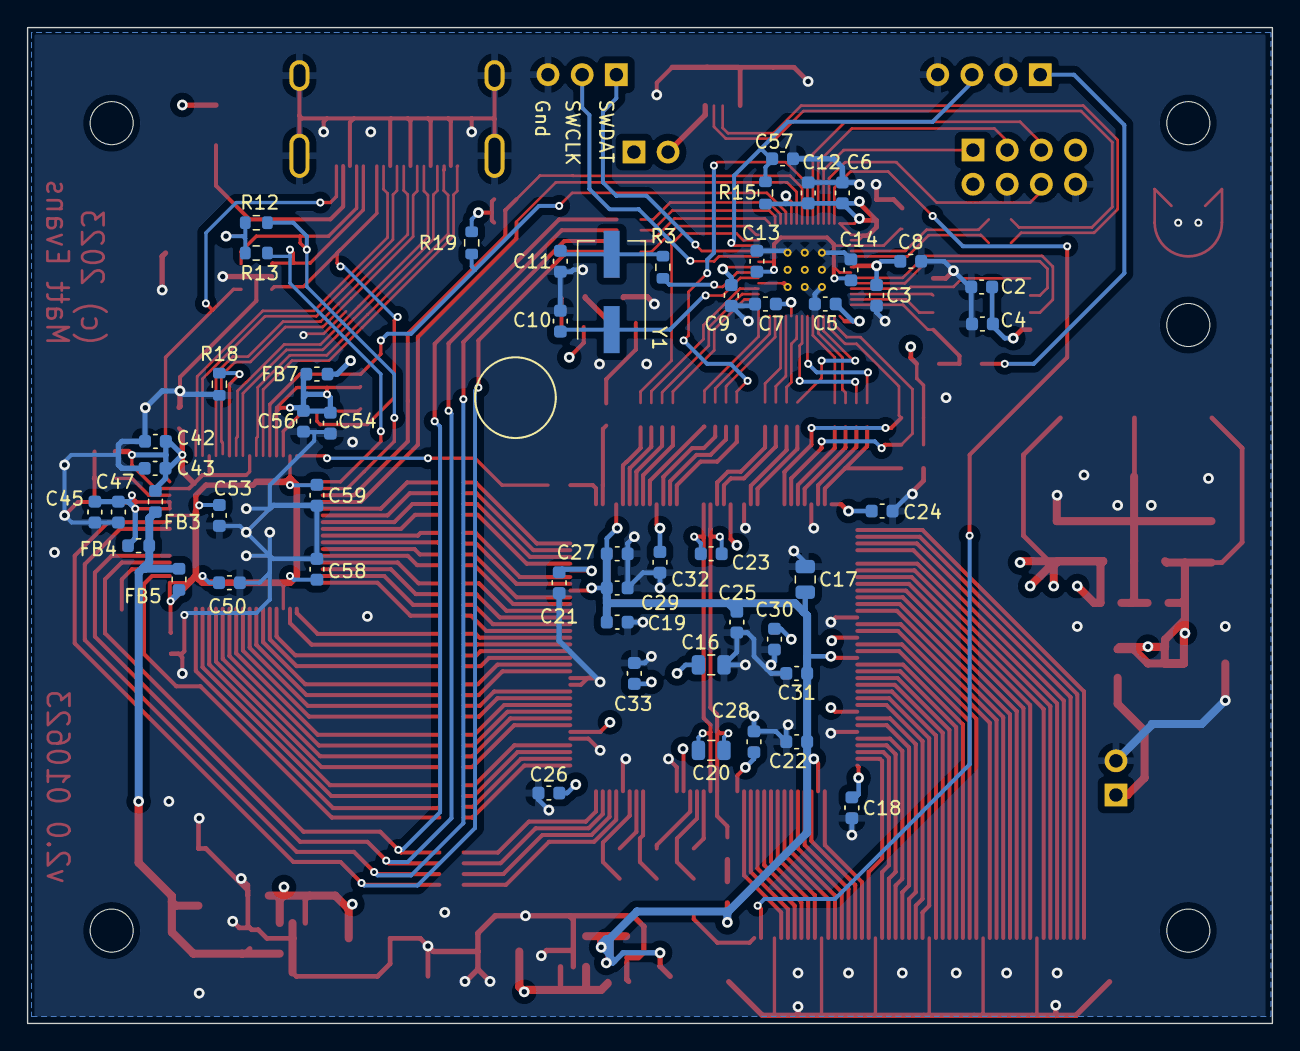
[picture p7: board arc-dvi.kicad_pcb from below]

Board: 4 copper layers, 92.5 x 74.0 mm, 142 parts (53 on the bottom side), 213 nets.

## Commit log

2022-06-20 v1.0 board
    [arc-dvi.kicad_pcb, arc-dvi.kicad_sch, fpga.kicad_sch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]
2022-07-07 Oops, no, _this_ is v1.0
    ;-)
    [arc-dvi.kicad_sch, fpga.kicad_sch]
2023-05-19 v2: ADV7513 and FFC
    Large work much progress - almost routed
    [arc-dvi.kicad_pcb, arc-dvi.kicad_sch, fpga.kicad_sch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]
2023-05-21 2.0 candiate: routed, looks neat, passes DRC
    DVI differential pairs aren't tuned that nicely, but 'probs ok'
    [arc-dvi.kicad_pcb, arc-dvi.kicad_sch, fpga.kicad_sch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]
2023-05-22 Tuned pairs (better, at least)
    [arc-dvi.kicad_pcb]
2023-05-22 Tweaked layout, marked plcc centre
    [arc-dvi.kicad_pcb]
2023-05-22 Moved Gnd TP, added decoration
    [arc-dvi.kicad_pcb]
2023-05-22 Updated date, made board narrower, added dims
    [arc-dvi.kicad_pcb]
2023-06-01 Made board slightly smaller, re-centered contact point, tidied
    Good to go, DRC clean.
    [arc-dvi.kicad_pcb]
2023-06-11 Add README, licence
    [arc-dvi.kicad_pcb, arc-dvi.kicad_sch]

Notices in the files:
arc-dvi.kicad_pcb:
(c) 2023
